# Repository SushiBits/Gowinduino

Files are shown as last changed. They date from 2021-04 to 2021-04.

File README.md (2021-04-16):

# Gowinduino

Gowinduino 是一款基于高云小蜜蜂 GW1NSR-4C 硬处理器 SoC FPGA 的试验开发板。

## 特性

GW1NSR-4C FPGA 有如下特性：

* 4608 个 LUT
* 3456 个寄存器
* 10 块 18kbit SRAM
* 256kbit 用户闪存
* 64Mbit PSRAM SiP
* 内置 Cortex-M3 硬 IP

本开发版有如下特性：

* 最高 12V 外部 DC 输入
* 3.3V I/O 电压
* Arduino Uno 脚位
* 集成 FT2232HL JTAG 和串口接口

## 授权许可

本作品是以[三条款 BSD 授权协议](LICENSE.md)授权的开源硬件。

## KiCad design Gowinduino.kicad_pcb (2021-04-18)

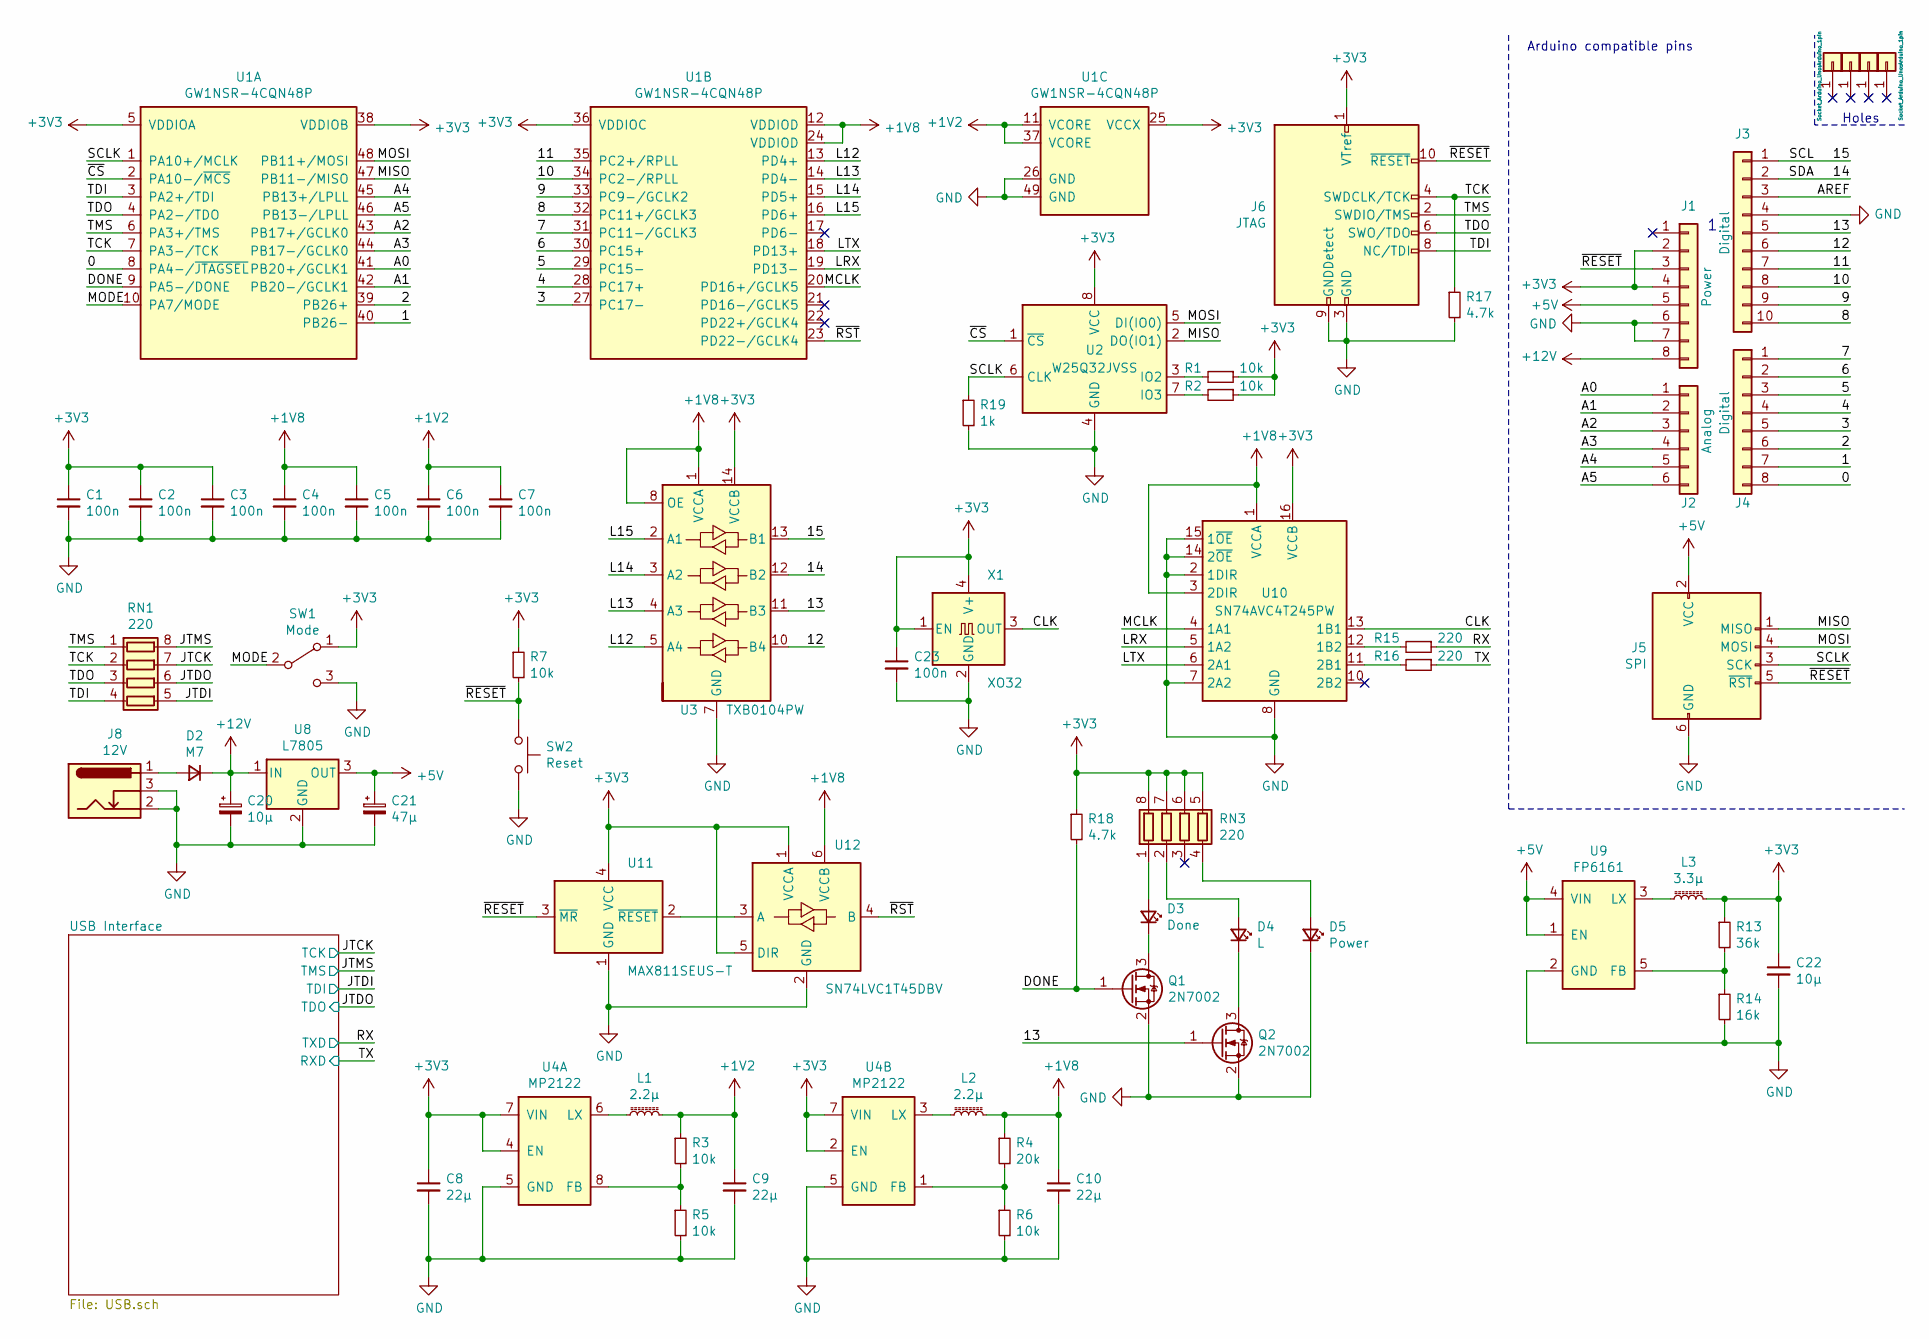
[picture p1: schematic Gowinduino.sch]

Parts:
C1, C2, C3, C4, C5, C6, C7, C23: 100n; C_0603_1608Metric_Pad1.08x0.95mm_HandSolder
C8, C9, C10: 22µ; C_0805_2012Metric_Pad1.18x1.45mm_HandSolder
C20: 10µ; CP_Elec_4x4.5
C21: 47µ; CP_Elec_4x4.5
C22: 10µ; C_0805_2012Metric_Pad1.18x1.45mm_HandSolder
D2: M7; D_SMA
D3: Done; LED_0805_2012Metric_Pad1.15x1.40mm_HandSolder
D4: L; LED_0805_2012Metric_Pad1.15x1.40mm_HandSolder
D5: Power; LED_0805_2012Metric_Pad1.15x1.40mm_HandSolder
J1: Power; PinSocket_1x08_P2.54mm_Vertical
J2: Analog; PinSocket_1x06_P2.54mm_Vertical
J3: Digital; PinSocket_1x10_P2.54mm_Vertical
J4: Digital; PinSocket_1x08_P2.54mm_Vertical
J5: SPI; PinHeader_2x03_P2.54mm_Vertical
J6: JTAG; PinHeader_2x05_P1.27mm_Vertical
J8: 12V; BarrelJack_Wuerth_6941xx301002
L1, L2: 2.2µ; L_0806_2014Metric_Pad1.15x1.60mm_HandSolder
L3: 3.3µ; L_0806_2014Metric_Pad1.15x1.60mm_HandSolder
PH1, PH2, PH3, PH4: CONN_01X01; Arduino_1pin
Q1, Q2: 2N7002; SOT-23
R1, R2, R3, R5, R6, R7: 10k; R_0603_1608Metric_Pad0.98x0.95mm_HandSolder
R4: 20k; R_0603_1608Metric_Pad0.98x0.95mm_HandSolder
R13: 36k; R_0603_1608Metric_Pad0.98x0.95mm_HandSolder
R14: 16k; R_0603_1608Metric_Pad0.98x0.95mm_HandSolder
R15, R16: 220; R_0603_1608Metric_Pad0.98x0.95mm_HandSolder
R17, R18: 4.7k; R_0603_1608Metric_Pad0.98x0.95mm_HandSolder
R19: 1k; R_0603_1608Metric_Pad0.98x0.95mm_HandSolder
RN1, RN3: 220; R_Array_Convex_4x0603
SW1: Mode; SW_SPDT_PCM12
SW2: Reset; SW_PUSH_6mm
U1: GW1NSR-4CQN48P; QFN-48-1EP_6x6mm_P0.4mm_EP4.2x4.2mm
U2: W25Q32JVSS; SOIC-8_5.23x5.23mm_P1.27mm
U3: TXB0104PW; TSSOP-14_4.4x5mm_P0.65mm
U4: MP2122; SOT-23-8
U8: L7805; TO-252-2
U9: FP6161; SOT-23-5
U10: SN74AVC4T245PW; TSSOP-16_4.4x5mm_P0.65mm
U11: MAX811SEUS-T; SOT-143
U12: SN74LVC1T45DBV; SOT-23-6
X1: XO32; Oscillator_SMD_EuroQuartz_XO32-4Pin_3.2x2.5mm

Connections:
+1V2: C6.1, C7.1, C9.1, L1.1, R3.1, U1.11 (VCORE), U1.37 (VCORE)
+1V8: C4.1, C5.1, C10.1, L2.1, R4.1, U1.12 (VDDIOD), U1.24 (VDDIOD), U3.1 (VCCA), U3.8 (OE), U10.1 (VCCA), U10.3 (2DIR), U12.6 (VCCB)
+3V3: C1.1, C2.1, C3.1, C8.1, C22.1, C23.1, J1.2, J1.4, J6.1 (VTref), L3.1, R1.1, R2.1, R7.1, R13.1, R18.1, RN3.5 (R4.2), RN3.6 (R3.2), RN3.7 (R2.2), RN3.8 (R1.2), SW1.1 (A), U1.5 (VDDIOA), U1.25 (VCCX), U1.36 (VDDIOC), U1.38 (VDDIOB), U2.8 (VCC), U3.14 (VCCB), U4.2 (EN), U4.4 (EN), U4.7 (VIN), U10.16 (VCCB), U11.4 (VCC), U12.1 (VCCA), U12.5 (DIR), X1.1 (EN), X1.4 (V+)
+5V: C21.1, J1.5, J5.2 (VCC), U8.3 (OUT), U9.1 (EN), U9.4 (VIN); also elsewhere on the board
+12V: C20.1, D2.1 (K), J1.8, U8.1 (IN)
/0: J4.8, U1.8 (PA4-/~JTAGSEL)
/1: J4.7, U1.40 (PB26-)
/2: J4.6, U1.39 (PB26+)
/3: J4.5, U1.27 (PC17-)
/4: J4.4, U1.28 (PC17+)
/5: J4.3, U1.29 (PC15-)
/6: J4.2, U1.30 (PC15+)
/7: J4.1, U1.31 (PC11-/GCLK3)
/8: J3.10, U1.32 (PC11+/GCLK3)
/9: J3.9, U1.33 (PC9-/GCLK2)
/10: J3.8, U1.34 (PC2-/RPLL)
/11: J3.7, U1.35 (PC2+/RPLL)
/12: J3.6, U3.10 (B4)
/13: J3.5, Q2.1 (G), U3.11 (B3)
/14: J3.2, U3.12 (B2)
/15: J3.1, U3.13 (B1)
/A0: J2.1, U1.41 (PB20+/GCLK1)
/A1: J2.2, U1.42 (PB20-/GCLK1)
/A2: J2.3, U1.43 (PB17+/GCLK0)
/A3: J2.4, U1.44 (PB17-/GCLK0)
/A4: J2.5, U1.45 (PB13+/LPLL)
/A5: J2.6, U1.46 (PB13-/LPLL)
/CLK: U10.13 (1B1), X1.3 (OUT)
/DONE: Q1.1 (G), R18.2, U1.9 (PA5-/DONE)
/JTCK: RN1.7 (R2.2); also elsewhere on the board
/JTDI: RN1.5 (R4.2); also elsewhere on the board
/JTDO: RN1.6 (R3.2); also elsewhere on the board
/JTMS: RN1.8 (R1.2); also elsewhere on the board
/L12: U1.13 (PD4+), U3.5 (A4)
/L13: U1.14 (PD4-), U3.4 (A3)
/L14: U1.15 (PD5+), U3.3 (A2)
/L15: U1.16 (PD6+), U3.2 (A1)
/LRX: U1.19 (PD13-), U10.5 (1A2)
/LTX: U1.18 (PD13+), U10.6 (2A1)
/MCLK: U1.20 (PD16+/GCLK5), U10.4 (1A1)
/MISO: J5.1 (MISO), U1.47 (PB11-/MISO), U2.2 (DO(IO1))
/MODE: SW1.2 (B), U1.10 (PA7/MODE)
/MOSI: J5.4 (MOSI), U1.48 (PB11+/MOSI), U2.5 (DI(IO0))
/RX: R15.1; also elsewhere on the board
/SCLK: J5.3 (SCK), R19.1, U1.1 (PA10+/MCLK), U2.6 (CLK)
/TCK: J6.4 (SWDCLK/TCK), R17.1, RN1.2 (R2.1), U1.7 (PA3-/TCK)
/TDI: J6.8 (NC/TDI), RN1.4 (R4.1), U1.3 (PA2+/TDI)
/TDO: J6.6 (SWO/TDO), RN1.3 (R3.1), U1.4 (PA2-/TDO)
/TMS: J6.2 (SWDIO/TMS), RN1.1 (R1.1), U1.6 (PA3+/TMS)
/TX: R16.1; also elsewhere on the board
/~CS: U1.2 (PA10-/~MCS), U2.1 (~CS)
/~RESET: J1.3, J5.5 (~RST), J6.10 (~RESET~), R7.2, SW2.1, U11.3 (~MR)
/~RST: U1.23 (PD22-/GCLK4), U12.4 (B)
GND: C1.2, C2.2, C3.2, C4.2, C5.2, C6.2, C7.2, C8.2, C9.2, C10.2, C20.2, C21.2, C22.2, C23.2, D5.1 (K), J1.6, J1.7, J3.4, J5.6 (GND), J6.3 (GND), J6.5 (GND), J6.9 (GNDDetect), J8.2, J8.3, Q1.2 (S), Q2.2 (S), R5.2, R6.2, R14.2, R17.2, R19.2, SW1.3 (C), SW2.2, U1.26 (GND), U1.49 (GND), U2.4 (GND), U3.7 (GND), U4.5 (GND), U8.2 (GND), U9.2 (GND), U10.2 (1DIR), U10.7 (2A2), U10.8 (GND), U10.9 (GND), U10.14 (2~OE), U10.15 (1~OE), U11.1 (GND), U12.2 (GND), X1.2 (GND); also elsewhere on the board
unnamed: D2.2 (A), J8.1
unnamed: D3.1 (K), Q1.3 (D)
unnamed: D3.2 (A), RN3.1 (R1.1)
unnamed: D4.1 (K), Q2.3 (D)
unnamed: D4.2 (A), RN3.2 (R2.1)
unnamed: D5.2 (A), RN3.4 (R4.1)
unnamed: L1.2, U4.6 (LX)
unnamed: L2.2, U4.3 (LX)
unnamed: L3.2, U9.3 (LX)
unnamed: R1.2, U2.3 (IO2)
unnamed: R2.2, U2.7 (IO3)
unnamed: R3.2, R5.1, U4.8 (FB)
unnamed: R4.2, R6.1, U4.1 (FB)
unnamed: R13.2, R14.1, U9.5 (FB)
unnamed: R15.2, U10.12 (1B2)
unnamed: R16.2, U10.11 (2B1)
unnamed: U11.2 (~RESET), U12.3 (A)

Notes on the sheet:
Holes
Arduino compatible pins

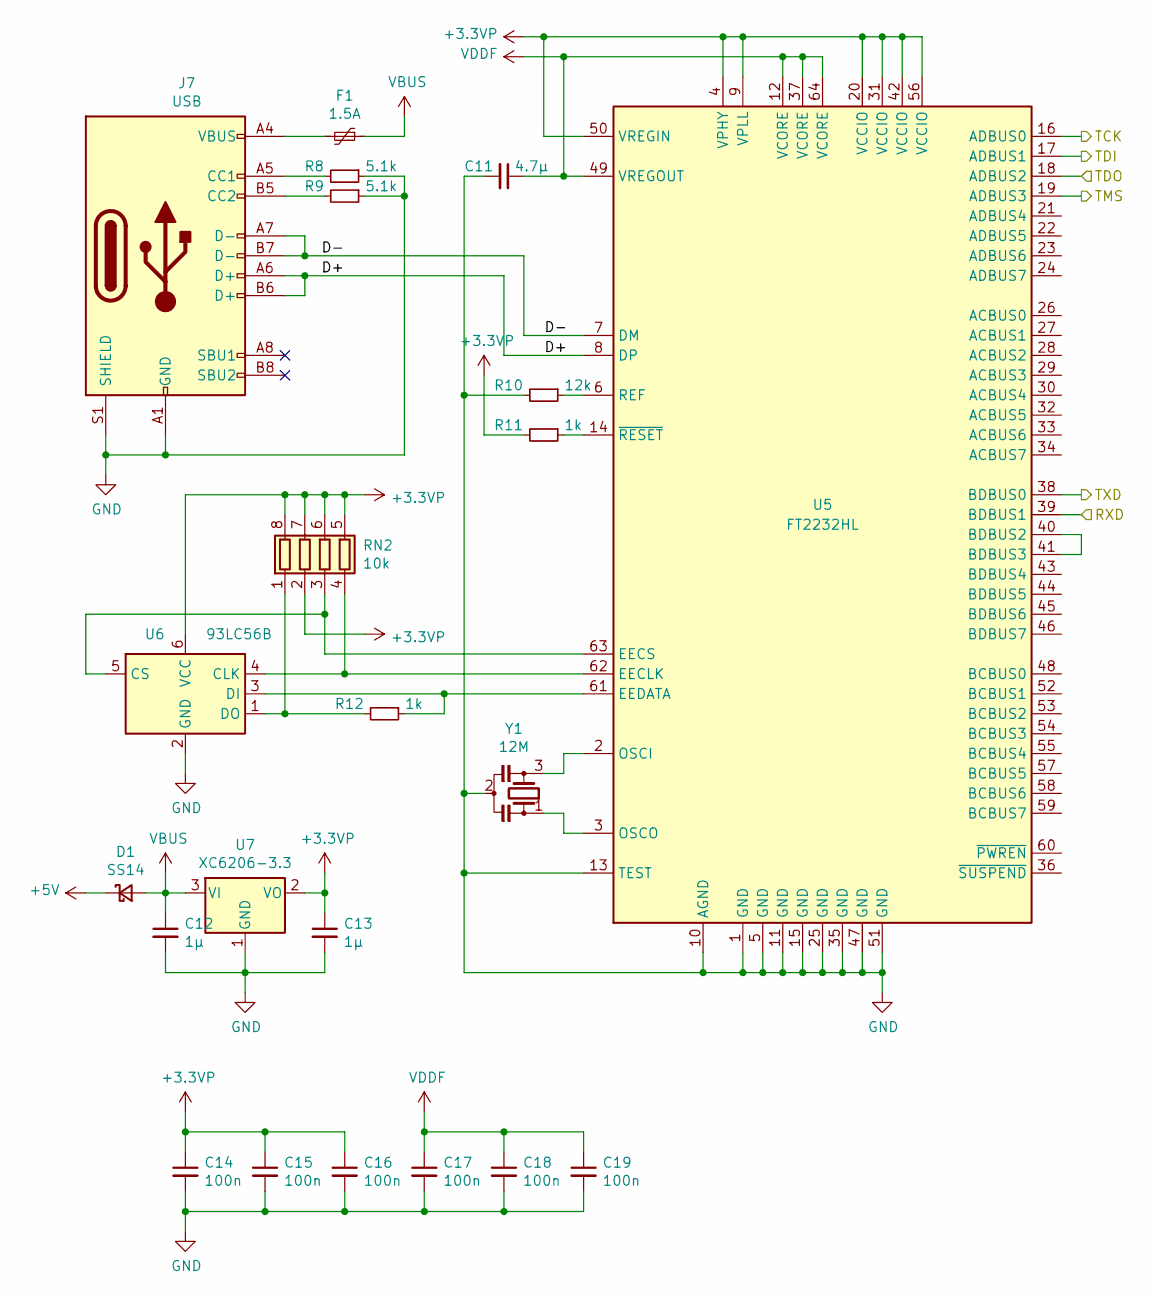
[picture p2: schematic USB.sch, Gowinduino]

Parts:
C11: 4.7µ; C_0603_1608Metric_Pad1.08x0.95mm_HandSolder
C12, C13: 1µ; C_0603_1608Metric_Pad1.08x0.95mm_HandSolder
C14, C15, C16, C17, C18, C19: 100n; C_0603_1608Metric_Pad1.08x0.95mm_HandSolder
D1: SS14; D_SMA
F1: 1.5A; Fuse_1812_4532Metric_Pad1.30x3.40mm_HandSolder
J7: USB; USB_C_Receptacle_HRO_TYPE-C-31-M-12
R8, R9: 5.1k; R_0603_1608Metric_Pad0.98x0.95mm_HandSolder
R10: 12k; R_0603_1608Metric_Pad0.98x0.95mm_HandSolder
R11, R12: 1k; R_0603_1608Metric_Pad0.98x0.95mm_HandSolder
RN2: 10k; R_Array_Convex_4x0603
U5: FT2232HL; LQFP-64_10x10mm_P0.5mm
U6: 93LC56B; SOT-23-6
U7: XC6206-3.3; SOT-23
Y1: 12M; Resonator_SMD_muRata_CSTxExxV-3Pin_3.0x1.1mm

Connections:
+3.3VP: C13.1, C14.1, C15.1, C16.1, R11.2, RN2.2 (R2.1), RN2.5 (R4.2), RN2.6 (R3.2), RN2.7 (R2.2), RN2.8 (R1.2), U5.4 (VPHY), U5.9 (VPLL), U5.20 (VCCIO), U5.31 (VCCIO), U5.42 (VCCIO), U5.50 (VREGIN), U5.56 (VCCIO), U6.6 (VCC), U7.2 (VO)
+5V: D1.1 (K); also elsewhere on the board
/JTCK: U5.16 (ADBUS0); also elsewhere on the board
/JTDI: U5.17 (ADBUS1); also elsewhere on the board
/JTDO: U5.18 (ADBUS2); also elsewhere on the board
/JTMS: U5.19 (ADBUS3); also elsewhere on the board
/RX: U5.38 (BDBUS0); also elsewhere on the board
/TX: U5.39 (BDBUS1); also elsewhere on the board
/USB Interface/D+: J7.A6 (D+), J7.B6 (D+), U5.8 (DP)
/USB Interface/D-: J7.A7 (D-), J7.B7 (D-), U5.7 (DM)
GND: C11.2, C12.2, C13.2, C14.2, C15.2, C16.2, C17.2, C18.2, C19.2, J7.A1 (GND), J7.A12 (GND), J7.B1 (GND), J7.B12 (GND), J7.S1 (SHIELD), R8.1, R9.1, R10.2, U5.1 (GND), U5.5 (GND), U5.10 (AGND), U5.11 (GND), U5.13 (TEST), U5.15 (GND), U5.25 (GND), U5.35 (GND), U5.47 (GND), U5.51 (GND), U6.2 (GND), U7.1 (GND), Y1.2; also elsewhere on the board
unnamed: F1.2, J7.A4 (VBUS), J7.A9 (VBUS), J7.B4 (VBUS), J7.B9 (VBUS)
unnamed: J7.A5 (CC1), R8.2
unnamed: J7.B5 (CC2), R9.2
unnamed: R10.1, U5.6 (REF)
unnamed: R11.1, U5.14 (~RESET)
unnamed: R12.1, U5.61 (EEDATA), U6.3 (DI)
unnamed: R12.2, RN2.1 (R1.1), U6.1 (DO)
unnamed: RN2.3 (R3.1), U5.63 (EECS), U6.5 (CS)
unnamed: RN2.4 (R4.1), U5.62 (EECLK), U6.4 (CLK)
unnamed: U5.2 (OSCI), Y1.3
unnamed: U5.3 (OSCO), Y1.1
unnamed: U5.40 (BDBUS2), U5.41 (BDBUS3)
VBUS: C12.1, D1.2 (A), F1.1, U7.3 (VI)
VDDF: C11.1, C17.1, C18.1, C19.1, U5.12 (VCORE), U5.37 (VCORE), U5.49 (VREGOUT), U5.64 (VCORE)

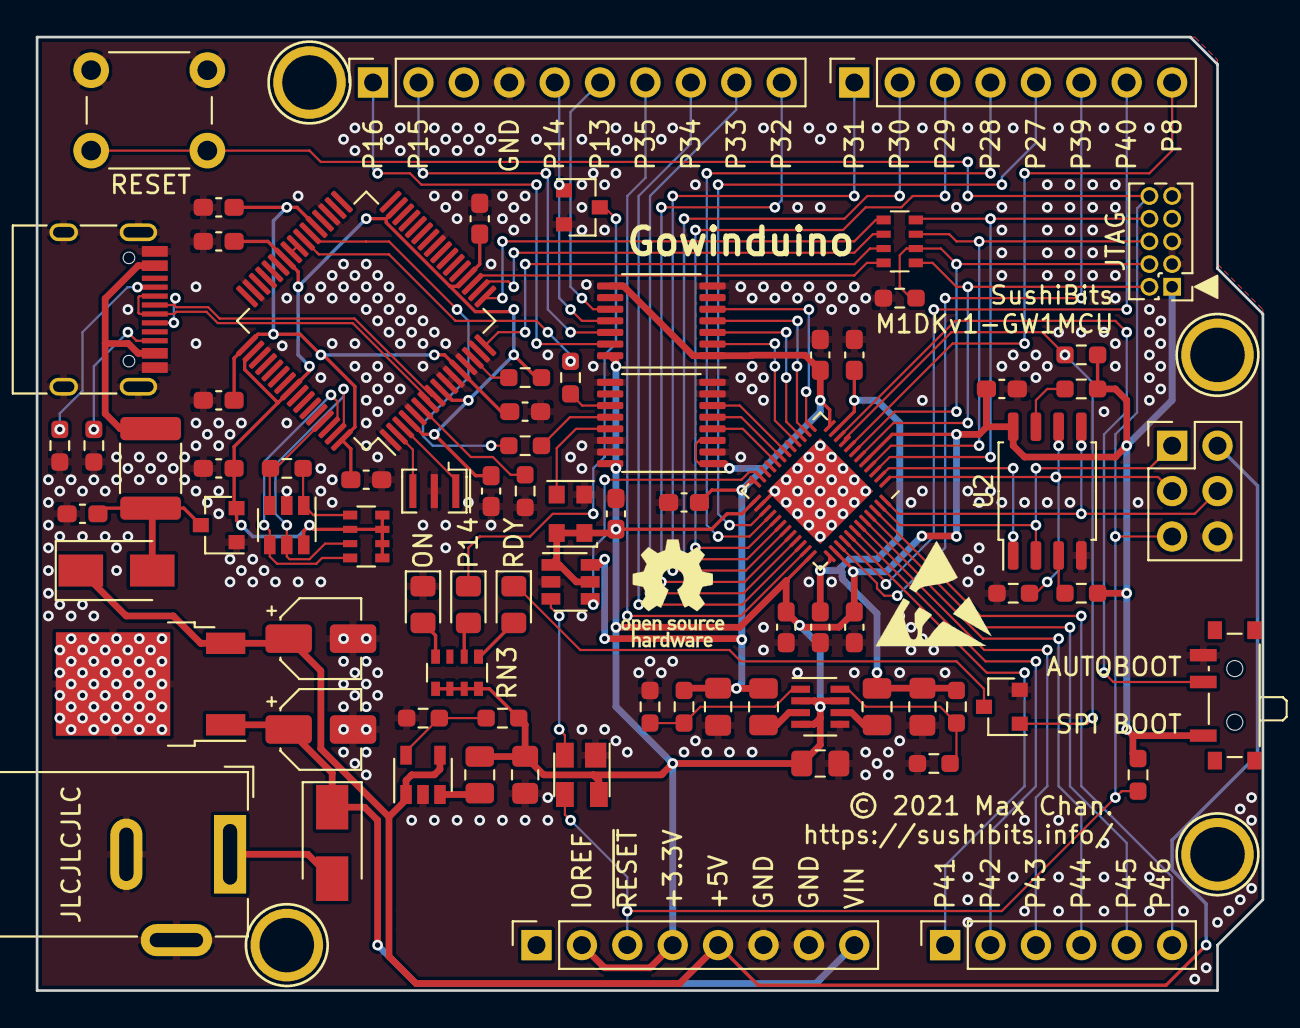
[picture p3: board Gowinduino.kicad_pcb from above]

Board: 2 copper layers, 68.6 x 53.3 mm, 84 parts (0 on the bottom side), 88 nets.

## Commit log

2021-04-16 Base KiCad Arduino Uno project
    [Gowinduino.kicad_pcb, Gowinduino.sch]
2021-04-16 Schematics: Introduced Arduino IO pins, FPGA and SPI Flash.
2021-04-16 PCB: Introduced Arduino pins.
    [Gowinduino.kicad_pcb]
2021-04-16 PCB: Introduced FPGA and SPI Flash
    [Gowinduino.kicad_pcb]
2021-04-16 Introduced JLCPCB DRC rules and GND fills
    [Gowinduino.kicad_pcb]
2021-04-16 PCB: Locating SPI Flash resistors.
    [Gowinduino.kicad_pcb]
2021-04-16 PCB: Hooking up the JTAG port.
    [Gowinduino.kicad_pcb, Gowinduino.sch]
2021-04-17 PCB: Hookup all 3.3V IO pins
    [Gowinduino.kicad_pcb, Gowinduino.sch]
2021-04-17 Implemented the 1.8V conversion out
    [Gowinduino.kicad_pcb, Gowinduino.sch]
2021-04-18 PCB: Wiring up all GPIO pins
    [Gowinduino.kicad_pcb, Gowinduino.sch, USB.sch]
2021-04-18 Implemented: USB and 12V VIN
    [Gowinduino.kicad_pcb, Gowinduino.sch]
2021-04-18 Via stitching at 5V regulator
    [Gowinduino.kicad_pcb]
2021-04-18 More via stitching at 5V regulator
    [Gowinduino.kicad_pcb]
2021-04-18 Various touchups around the PCB.
    [Gowinduino.kicad_pcb, Gowinduino.sch]
2021-04-18 Schematics: LEDs
    [Gowinduino.kicad_pcb, Gowinduino.sch]
2021-04-18 PCB: Layout done, now stitching vias
    [Gowinduino.kicad_pcb, Gowinduino.sch]
2021-04-18 FInals: front-side silkscreens
    [Gowinduino.kicad_pcb, Gowinduino.sch]
2021-04-18 Name on the drawings
    [Gowinduino.kicad_pcb, Gowinduino.sch, USB.sch]
2021-04-18 OSHW and ESD symbols
    [Gowinduino.kicad_pcb, Gowinduino.sch]

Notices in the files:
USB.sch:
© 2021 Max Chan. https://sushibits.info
